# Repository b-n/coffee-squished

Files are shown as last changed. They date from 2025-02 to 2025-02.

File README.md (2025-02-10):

# Coffee-Squished

A coffee WDT tool built using FreeCAD 1.0.

- `./Fancy` contains the fancy version which requires the Curves Workbench.
- `./NoCurves` contains the version without the fancy cutout, and just needs vanilla FreeCAD.

Inspiration from many spirograph WDT tools, but I wanted to make one as compact as possible,
without the need for any extra parts.

FreeCAD docs are full constrained with adjustable parameters.

## BOM

- Filament
- 1x 6813 bearing. 85mm OD, 65mm ID, 10mm height
- 8x MR63ZZ ball bearings. 6mm OD, 3mm ID, 2.5mm height
- 4x M3x12mm screws (could probably get away with 10mm, but I had 12mm on hand)
- 10x accupuncture needles. Handle is 1.4mm thick. I used 0.35mm, but 0.25mm might be better for
  more flex on the needles.
- Some epoxy

Assembly:

1. Print all the things (I used 40% infill, "transparent" PLA)
1. Find a way to cut down the needles. My needles did not like having their handle shortened, thus
   the epoxy. There is probably a better way to do this, but this is what I did...
1. Assemble all the things.

Note:

- Most things are press fix. This includes the small bearings. You may want to tighten the bearings
  together with a bolt and nut first to aid it in if your tolerances are too tight.
- Do not poke you eyes out. Needles are sharp. Cut the needles down to fit

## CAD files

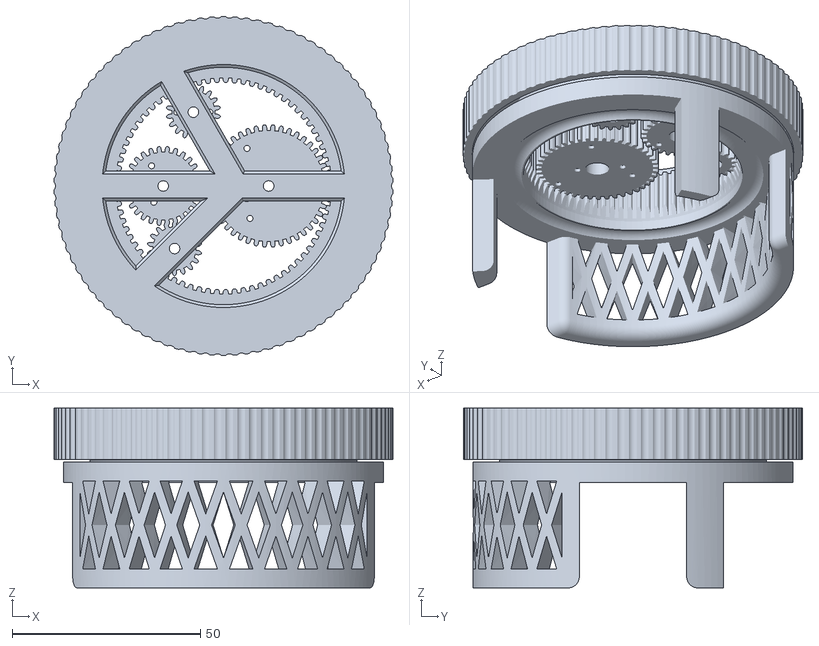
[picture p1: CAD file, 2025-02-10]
Fancy/Coffee-Squished-Fancy-Full.stl
90.0 x 90.0 x 47.7

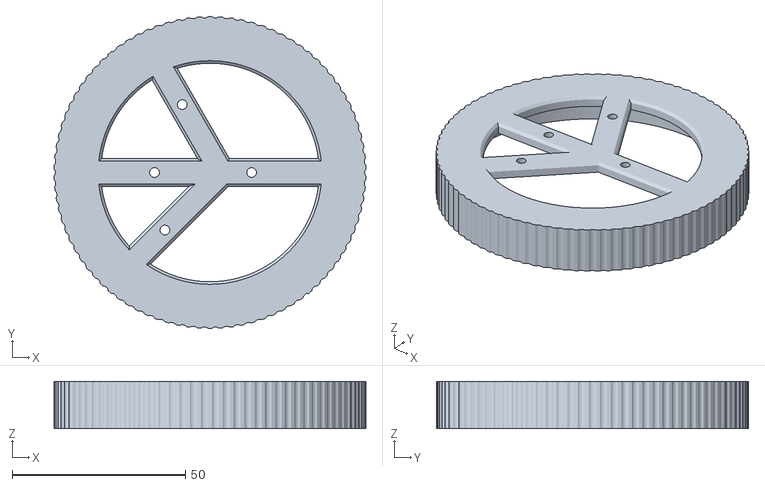
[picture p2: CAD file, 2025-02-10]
NoCurves/Coffee-Squished-NoCurves-TopHousing.stl
90.0 x 90.0 x 13.6

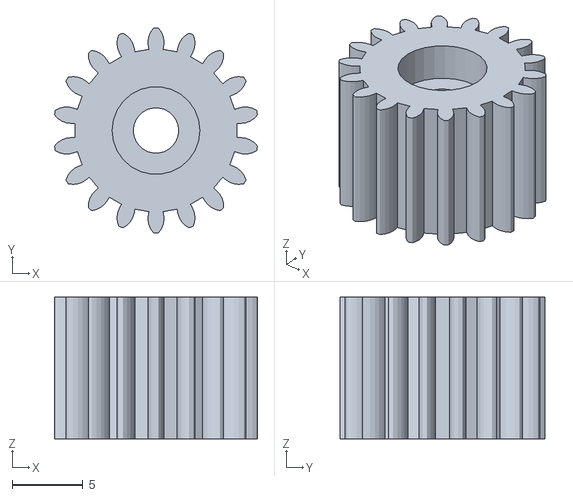
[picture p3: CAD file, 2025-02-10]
NoCurves/Coffee-Squished-NoCurves-SmolGear1.stl
14.3 x 14.5 x 10.0

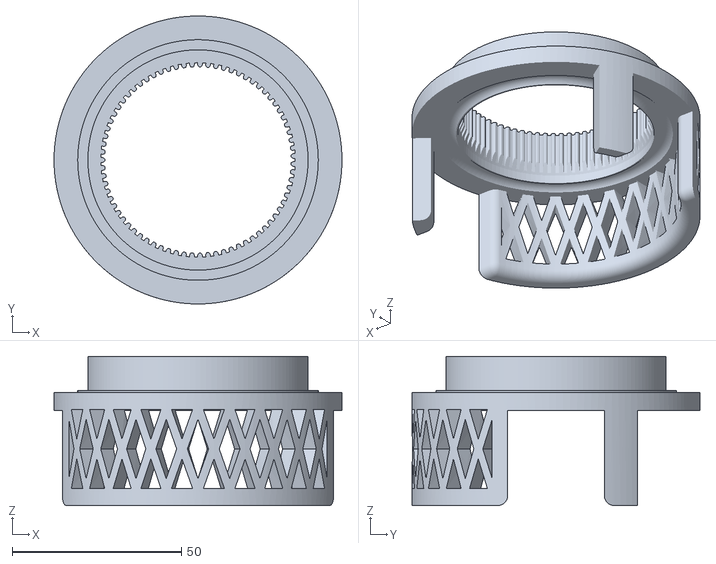
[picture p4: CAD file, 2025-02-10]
Fancy/Coffee-Squished-Fancy-Potafiltergear.stl
85.0 x 85.0 x 44.0

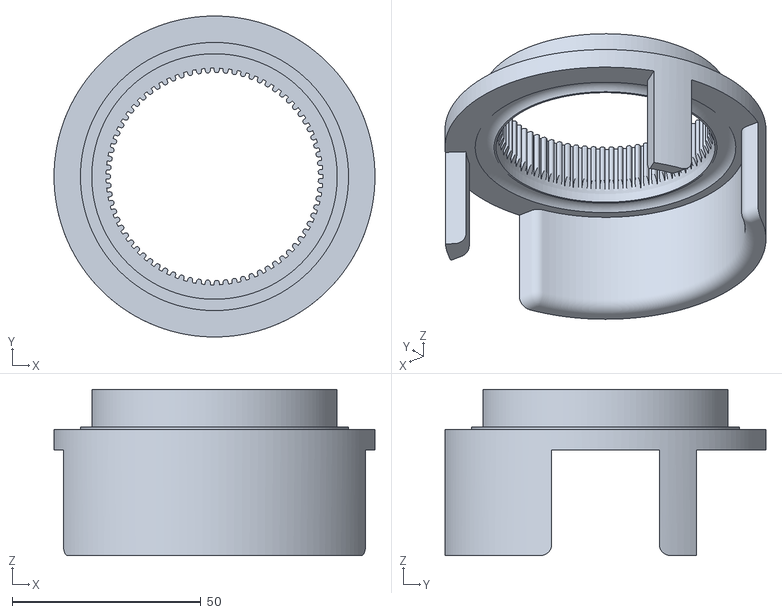
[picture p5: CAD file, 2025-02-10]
NoCurves/Coffee-Squished-NoCurves-Potafiltergear.stl
85.0 x 85.0 x 44.0

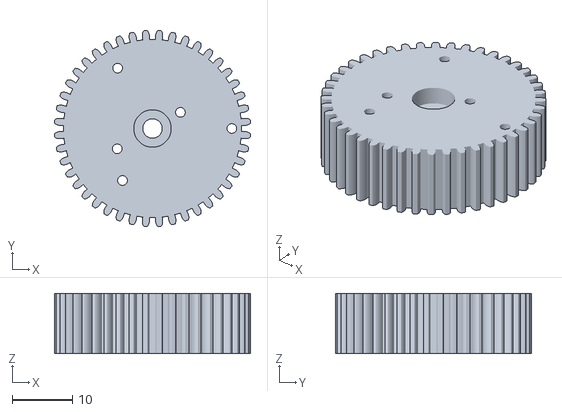
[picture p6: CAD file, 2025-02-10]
Fancy/Coffee-Squished-Fancy-LargeGear.stl
32.5 x 32.5 x 10.0

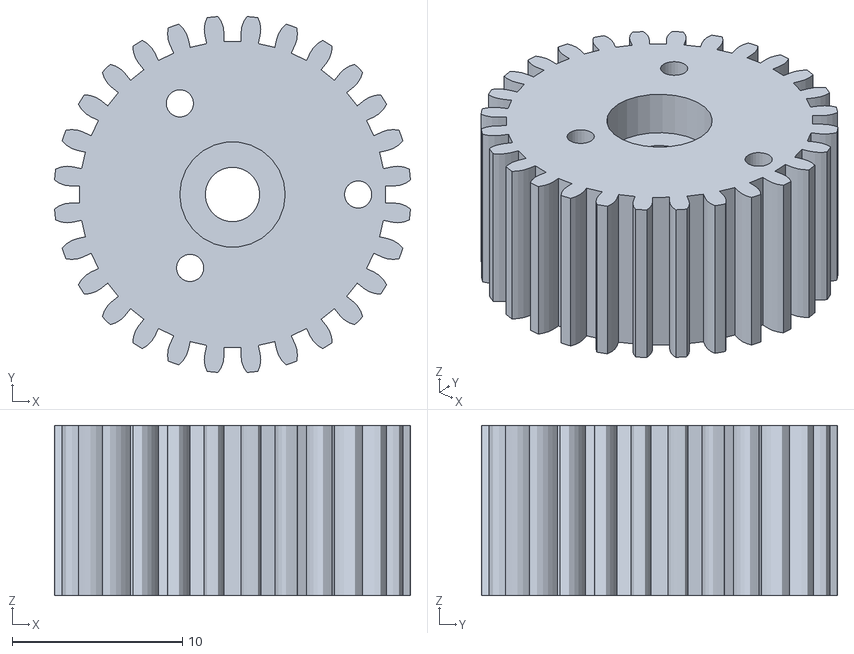
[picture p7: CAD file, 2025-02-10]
NoCurves/Coffee-Squished-NoCurves-MediumGear.stl
20.9 x 20.9 x 10.0

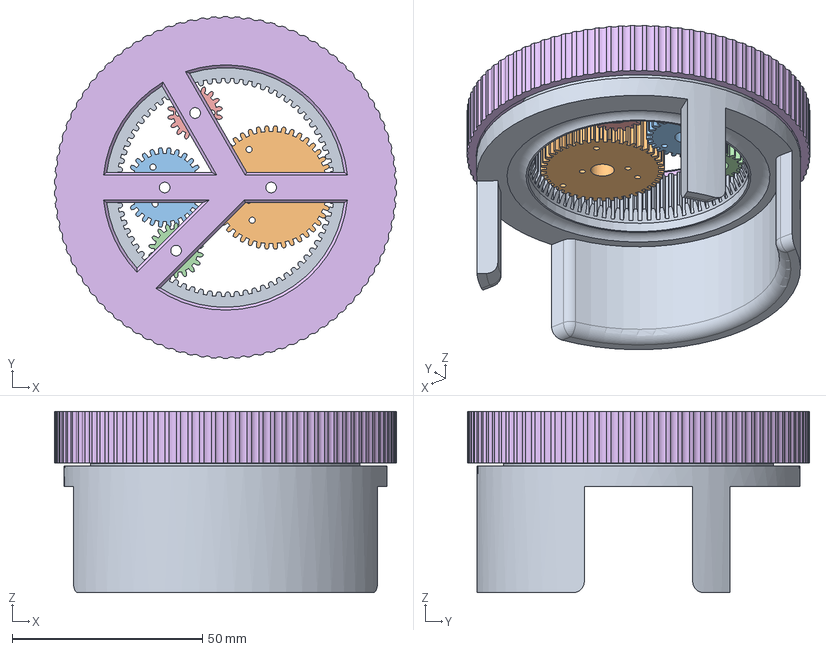
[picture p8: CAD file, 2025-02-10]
NoCurves/Coffee-Squished-NoCurves.FCStd
90.0 x 90.0 x 47.7 mm

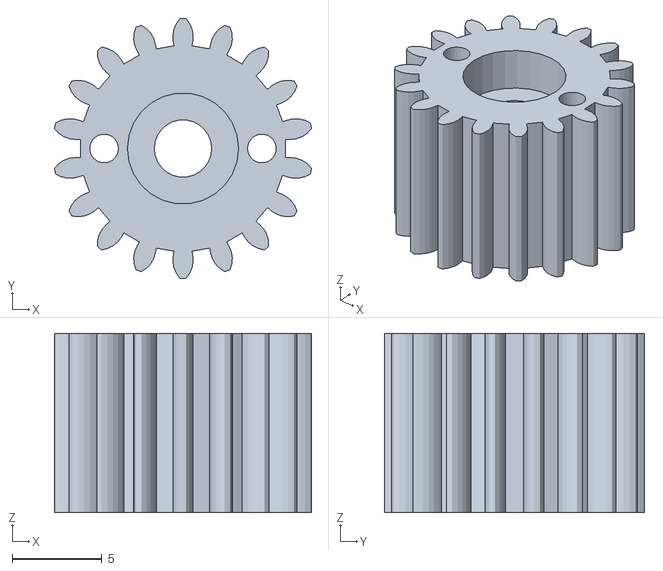
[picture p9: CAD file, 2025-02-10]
Fancy/Coffee-Squished-Fancy-SmolGear2.stl
14.3 x 14.5 x 10.0

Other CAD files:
Fancy/Coffee-Squished-Fancy.FCStd
NoCurves/Coffee-Squished-NoCurves-SmolGear2.stl
Fancy/Coffee-Squished-Fancy-MediumGear.stl

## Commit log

2025-02-10 It all works!
    [Coffee-Squished-Fancy-LargeGear.stl, Coffee-Squished-Fancy-MediumGear.stl, Coffee-Squished-Fancy-Potafiltergear.stl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]
2025-02-10 Add in full assemblies
    [Coffee-Squished-Fancy-Full.stl]
